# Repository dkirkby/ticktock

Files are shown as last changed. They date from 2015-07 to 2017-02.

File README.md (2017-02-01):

# Precision Pendulum Clock Metrology

This repository contains electronics schematics and a printed circuit board design for precision metrology of a pendulum clock.

The corresponding microcontroller firmware and unix server backend are hosted [here](https://github.com/captainkirkby/Gears).

For an overview of this project, see [this excerpt](https://github.com/dkirkby/ticktock/blob/master/InterfaceMagazineFall2015.pdf) from the Fall 2015 Issue of the [CalIT2](http://www.calit2.uci.edu) Interface Magazine.

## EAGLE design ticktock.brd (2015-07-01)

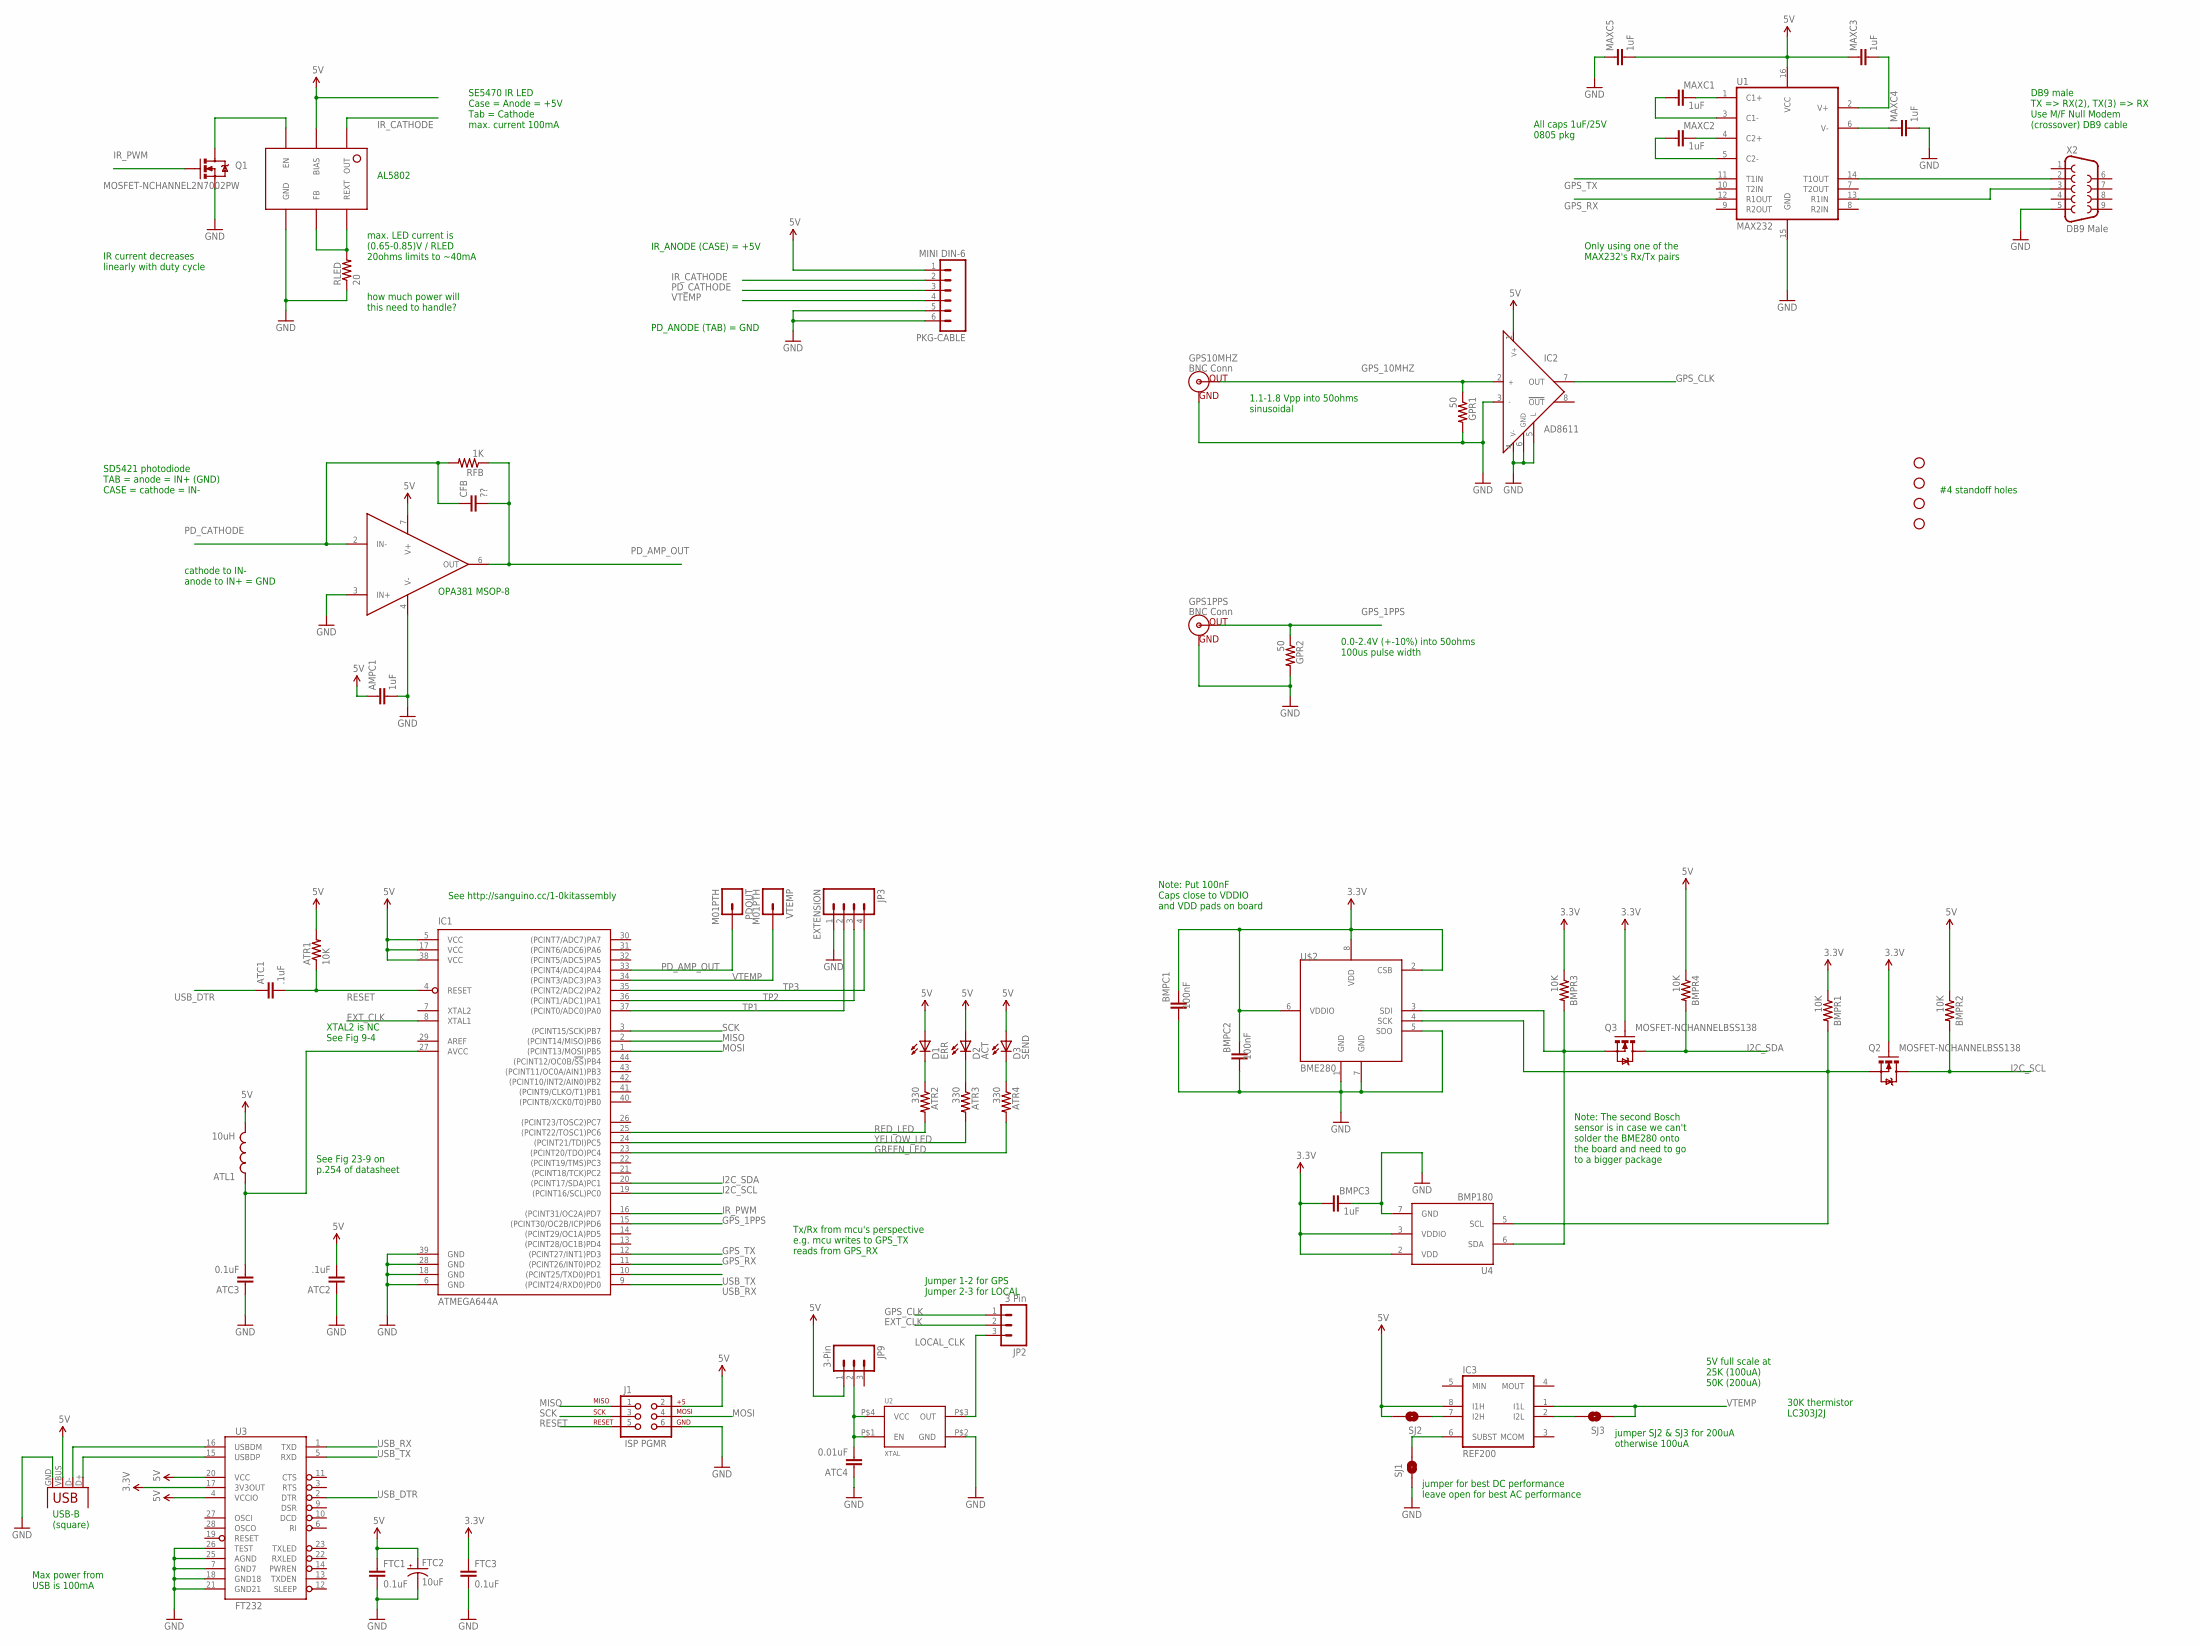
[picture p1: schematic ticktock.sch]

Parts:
AMPC1: 1uF; 0805
ATC1, ATC2: .1uF; 0805
ATC3: 0.1uF; 0805
ATC4: 0.01uF; 0805
ATL1: 10uH; 0805
ATR1: 10K; 0805
ATR2, ATR3, ATR4: 330; 0805
BMPC1, BMPC2: 100nF; 0805
BMPC3: 1uF; 0805
BMPR1, BMPR2, BMPR3, BMPR4: 10K; 0805
CFB: ??; 0805
D1: ERR; LED-1206
D2: ACT; LED-1206
D3: SEND; LED-1206
FTC1, FTC3: 0.1uF; 0805
FTC2: 10uF; EIA3216
GPR1, GPR2: 50; 0805
GPS1PPS, GPS10MHZ: BNC Conn; BNC
IC1: ATMEGA644A; TQFP44
IC2: AD8611; MSOP08
IC3: REF200; SO08
IC4: OPA381; MSOP08
IC5: AL5802
J1: ISP PGMR; 2X3-NS
JP1: Square USB; USB-B-PTH
JP2: 3 Pin; 1X03_LOCK
JP3: EXTENSION; 1X04_LOCK
JP9: 3-Pin; 1X03_LOCK
MAXC1, MAXC2, MAXC3, MAXC4, MAXC5: 1uF; 0805
PDOUT: M01PTH; 1X01
PKG-CABLE: MINI DIN-6; MINI-DIN6
Q1: MOSFET-NCHANNEL2N7002PW; SOT323
Q2, Q3: MOSFET-NCHANNELBSS138; SOT23
RFB: 1K; 0805
RLED: 20; 0805
SJ1, SJ2, SJ3: SOLDERJUMPERNO; SJ_2S-NO
STANDOFF1, STANDOFF2, STANDOFF3, STANDOFF4: STAND-OFF
U1: MAX232; SO016
U2: XTAL; CRYSTAL-SMD-7X5
U3: FT232; SSOP28DB
U4: BMP180
U$2: BME280
VTEMP: M01PTH; 1X01
X2: DB9 Male; DB9_MALE

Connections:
3.3V: BMPC1.2, BMPC2.2, BMPC3.1, BMPR1.1, BMPR3.1, FTC3.1, Q2.1 (G), Q3.1 (G), U3.17 (3V3OUT), U4.2 (VDD), U4.3 (VDDIO), U$2.2 (CSB), U$2.6 (VDDIO), U$2.8 (VDD)
5V: AMPC1.1, ATC2.2, ATL1.2, ATR1.2, BMPR2.1, BMPR4.1, D1.A, D2.A, D3.A, FTC1.1, FTC2.A (+), IC1.5 (VCC), IC1.17 (VCC), IC1.38 (VCC), IC2.1 (V+), IC3.8 (I1H), IC4.7 (V+), IC5.BIAS, J1.2, JP1.VBUS, JP9.1, MAXC3.1, MAXC5.2, PKG-CABLE.1, SJ2.2, U1.16 (VCC), U3.4 (VCCIO), U3.20 (VCC)
EXT_CLK: IC1.8 (XTAL1), JP2.2
GND: AMPC1.2, ATC2.1, ATC3.1, ATC4.1, BMPC1.1, BMPC2.1, BMPC3.2, FTC1.2, FTC2.C (-), FTC3.2, GPR1.2, GPR2.2, GPS1PPS.GND, GPS10MHZ.GND, IC1.6 (GND), IC1.18 (GND), IC1.28 (GND), IC1.39 (GND), IC2.3 (IN-), IC2.4 (V-), IC2.5 (L), IC2.6 (GND), IC4.3 (IN+), IC4.4 (V-), IC5.GND, J1.6, JP1.GND, JP3.1, MAXC4.2, MAXC5.1, PKG-CABLE.5, PKG-CABLE.6, Q1.2 (S), RLED.1, SJ1.1, U1.15 (GND), U2.P$2 (GND), U3.7 (GND7), U3.18 (GND18), U3.21 (GND21), U3.25 (AGND), U3.26 (TEST), U4.7 (GND), U$2.1 (GND), U$2.5 (SDO), U$2.7 (GND), X2.5
GPS_1PPS: GPR2.1, GPS1PPS.S (OUT), IC1.15 ((PCINT30/OC2B/ICP)PD6)
GPS_10MHZ: GPR1.1, GPS10MHZ.S (OUT), IC2.2 (IN+)
GPS_CLK: IC2.7 (OUT), JP2.1
GPS_RX: IC1.11 ((PCINT26/INT0)PD2), U1.12 (R1OUT)
GPS_TX: IC1.12 ((PCINT27/INT1)PD3), U1.11 (T1IN)
GREEN_LED: ATR4.2, IC1.23 ((PCINT20/TDO)PC4)
I2C_SCL: BMPR2.2, IC1.19 ((PCINT16/SCL)PC0), Q2.3 (D)
I2C_SDA: BMPR4.2, IC1.20 ((PCINT17/SDA)PC1), Q3.3 (D)
IR_CATHODE: IC5.OUT, PKG-CABLE.2
IR_PWM: IC1.16 ((PCINT31/OC2A)PD7), Q1.1 (G)
LOCAL_CLK: JP2.3, U2.P$3 (OUT)
MISO: IC1.2 ((PCINT14/MISO)PB6), J1.1
MOSI: IC1.1 ((PCINT13/MOSI)PB5), J1.4
unnamed: IC5.EN, Q1.3 (D)
unnamed: IC5.FB, IC5.REXT, RLED.2
unnamed: MAXC1.2, U1.1 (C1+)
unnamed: MAXC1.1, U1.3 (C1-)
unnamed: MAXC2.2, U1.4 (C2+)
unnamed: MAXC2.1, U1.5 (C2-)
unnamed: MAXC3.2, U1.2 (V+)
unnamed: U1.14 (T1OUT), X2.2
unnamed: MAXC4.1, U1.6 (V-)
unnamed: U1.13 (R1IN), X2.3
unnamed: JP1.D-, U3.16 (USBDM)
unnamed: JP1.D+, U3.15 (USBDP)
unnamed: ATC3.2, ATL1.1, IC1.27 (AVCC)
unnamed: IC3.6 (SUBST), SJ1.2
unnamed: BMPR1.2, Q2.2 (S), U4.5 (SCL), U$2.4 (SCK)
unnamed: ATR4.1, D3.C
unnamed: IC3.7 (I2H), SJ2.1
unnamed: IC3.2 (I2L), SJ3.2
unnamed: ATR3.1, D2.C
unnamed: ATR2.1, D1.C
unnamed: ATC4.2, JP9.2, U2.P$1 (EN), U2.P$4 (VCC)
unnamed: BMPR3.2, Q3.2 (S), U4.6 (SDA), U$2.3 (SDI)
PD_AMP_OUT: CFB.2, IC1.33 ((PCINT4/ADC4)PA4), IC4.6 (OUT), PDOUT.1, RFB.1
PD_CATHODE: CFB.1, IC4.2 (IN-), PKG-CABLE.3, RFB.2
RED_LED: ATR2.2, IC1.25 ((PCINT22/TOSC1)PC6)
RESET: ATC1.2, ATR1.1, IC1.4 (RESET), J1.5
SCK: IC1.3 ((PCINT15/SCK)PB7), J1.3
TP1: IC1.37 ((PCINT0/ADC0)PA0), JP3.2
TP2: IC1.36 ((PCINT1/ADC1)PA1), JP3.3
TP3: IC1.35 ((PCINT2/ADC2)PA2), JP3.4
USB_DTR: ATC1.1, U3.2 (DTR)
USB_RX: IC1.9 ((PCINT24/RXD0)PD0), U3.1 (TXD)
USB_TX: IC1.10 ((PCINT25/TXD0)PD1), U3.5 (RXD)
VTEMP: IC1.34 ((PCINT3/ADC3)PA3), IC3.1 (I1L), PKG-CABLE.4, SJ3.1, VTEMP.1
YELLOW_LED: ATR3.2, IC1.24 ((PCINT21/TDI)PC5)

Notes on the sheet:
max. LED current is (0.65-0.85)V / RLED 20ohms limits to ~40mA
SE5470 IR LED Case = Anode = +5V Tab = Cathode max. current 100mA
how much power will this need to handle?
IR current decreases linearly with duty cycle
AL5802
All caps 1uF/25V 0805 pkg
Only using one of the MAX232's Rx/Tx pairs
DB9 male TX => RX(2), TX(3) => RX Use M/F Null Modem (crossover) DB9 cable
USB-B (square)
Max power from USB is 100mA
See Fig 23-9 on p.254 of datasheet
IR_ANODE (CASE) = +5V
XTAL2 is NC See Fig 9-4
See http://sanguino.cc/1-0kitassembly
Jumper 1-2 for GPS Jumper 2-3 for LOCAL
0.0-2.4V (+-10%) into 50ohms 100us pulse width
1.1-1.8 Vpp into 50ohms sinusoidal
OPA381 MSOP-8
cathode to IN- anode to IN+ = GND
SD5421 photodiode TAB = anode = IN+ (GND) CASE = cathode = IN-
PD_ANODE (TAB) = GND
jumper for best DC performance leave open for best AC performance
jumper SJ2 & SJ3 for 200uA otherwise 100uA
5V full scale at 25K (100uA) 50K (200uA)
30K thermistor LC303J2J
#4 standoff holes
Note: Put 100nF Caps close to VDDIO and VDD pads on board
Note: The second Bosch sensor is in case we can't solder the BME280 onto the board and need to go to a bigger package
Tx/Rx from mcu's perspective e.g. mcu writes to GPS_TX reads from GPS_RX

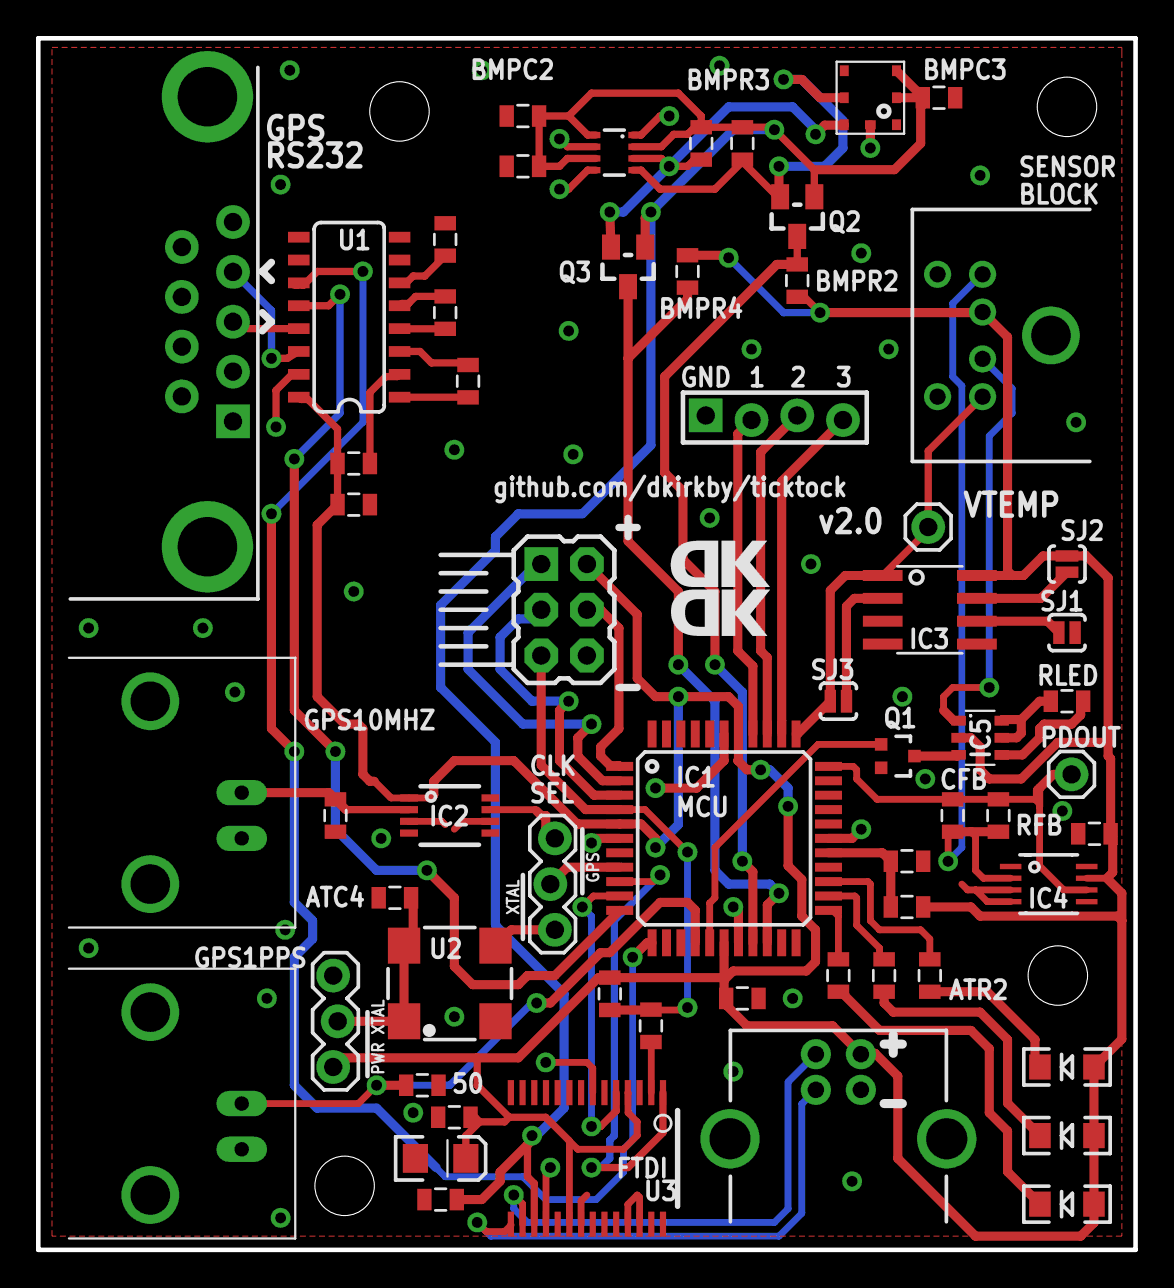
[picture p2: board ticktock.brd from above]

Board: 2 copper layers, 61.0 x 67.3 mm, 64 parts (0 on the bottom side), 52 nets.

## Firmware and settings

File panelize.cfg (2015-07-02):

# This configuration file demonstrates panelizing a single job.

##############################################################################
# In the [DEFAULT] section you can create global names to save typing the same
# directory name, for example, over and over.
##############################################################################
[DEFAULT]

# Change projdir to wherever your project files are, for example:
#
#   projdir = /home/stuff/projects/test
#
# or relative pathname from where you are running GerbMerge
#
#   projdir = testdata
#
# or if all files are in the current directory (as in this example):
#
#   projdir = .
projdir = .

# For convenience, this is the base name of the merged output files.
MergeOut = merge9

#############################################################################
# The [Options] section defines settings that control how the input files are
# read and how the output files are generated.
#############################################################################
[Options]

################################################################
#
#               Settings that are very important
#
################################################################

# Option indicating name of file that maps Excellon tool codes to drill sizes.
# This is not necessary if the Excellon files have embedded tool sizes, or if a
# tool list is specified as part of the job description. The ToolList option
# here is the "last resort" for mapping tool codes to tool sizes. Most recent
# PCB programs embed drill size information right in the Excellon file, so this
# option should not be necessary and can be commented out.
#ToolList=proj1.drl

# Optional indication of the number of decimal places in input Excellon drill
# files. The default is 4 which works for recent versions of Eagle (since
# version 4.11r12), as well as Orcad and PCB. Older versions of Eagle use 3
# decimal places.
#ExcellonDecimals = 4

################################################################
#
#             Settings that are somewhat important
#
################################################################

# Which layers to draw cut lines on. Omit this option or set to 'None' for no
# cut lines. Cut lines are borders around each job that serve as guides for
# cutting the panel into individual jobs. Option 'CutLineWidth' sets the
# thickness of these cut lines.
#
# NOTE: Layer names are ALL LOWERCASE, even if you define them with uppercase
# letters below.
CutLineLayers = *topsilkscreen

# Which layers to draw crop marks on. Omit this option or set to 'None' for no
# crop marks. Crop marks are small L-shaped marks at the 4 corners of the final
# panel. These practically define the extents of the panel and are required by
# some board manufacturers. Crop marks are also required if you want to leave
# extra space around the final panel for tooling or handling.  Option
# 'CropMarkWidth' sets the thickness of these crop marks.
#
# NOTE: Layer names are ALL LOWERCASE, even if you define them with uppercase
# letters below.
CropMarkLayers = *topsilkscreen

# Set this option to the name of a file in which to write a Gerber fabrication
# drawing. Some board manufacturers require a fabrication drawing with panel
# dimensions and drill hit marks and drill legend. There's no harm in creating
# this file...you can ignore it if you don't need it.
FabricationDrawingFile = %(projdir)s/%(mergeout)s/%(mergeout)s.fab

# If FabricationDrawingFile is specified, you can provide an optional file name
# of a file containing arbitrary text to add to the fabrication drawing. This
# text can indicate manufacturing information, contact information, etc.
#FabricationDrawingText = %(projdir)s/fabdwg.txt

# Option to generate leading zeros in the output Excellon drill file, i.e., to
# NOT use leading-zero suppression. Some Gerber viewers cannot properly guess
# the Excellon file format when there are no leading zeros.  Set this option to
# 1 if your Gerber viewer is putting the drill holes in far off places that do
# not line up with component pads.
ExcellonLeadingZeros = 0

# Optional additional Gerber layer on which to draw a rectangle defining the
# extents of the entire panelized job. This will create a Gerber file (with
# name specified by this option) that simply contains a rectangle defining the
# outline of the final panel. This outline file is useful for circuit board
# milling to indicate a path for the router tool. There's no harm in creating
# this file...you can ignore it if you don't need it.
OutlineLayerFile = %(projdir)s/%(mergeout)s/%(mergeout)s.oln

# Optional additional Gerber layer on which to draw horizontal and vertical
# lines describing where to score (i.e., V-groove) the panel so that jobs
# can easily snap apart. These scoring lines will be drawn half-way between
# job borders.
ScoringFile = %(projdir)s/%(mergeout)s/%(mergeout)s.sco
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

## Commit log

2013-12-06 Add schematic with 8.5x11 landscape frame
    [ticktock.sch]
2013-12-06 Add 2x2 grid of schematic frames
    [ticktock.sch]
2013-12-06 Add power nodes from sparkfun git library
    [ticktock.sch]
2013-12-07 add some components for the LED driver
    [ticktock.sch]
2013-12-07 create initial board file
    [ticktock.brd]
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2013-12-18 Finish IR led current source
    [ticktock.brd, ticktock.sch]
2013-12-18 add mini-DIN6 connector to package
    [ticktock.brd, ticktock.sch]
2013-12-18 Add RS232 transceiver and DB9 connector
    [ticktock.brd, ticktock.sch]
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2013-12-18 Add BNC connectors and AVR644
    [ticktock.brd, ticktock.sch]
2013-12-18 Add FTDI USB interface
    [ticktock.brd, ticktock.sch]
2013-12-18 Add MCU power and reset
    [ticktock.brd, ticktock.sch]
2013-12-19 Add some MCU connections
    [ticktock.brd, ticktock.sch]
2013-12-19 Add local 10MHz osc and local/gps jumper block
    [ticktock.brd, ticktock.sch]
2013-12-19 Add comparator for GPS 10MHz
    [ticktock.brd, ticktock.sch]
2013-12-19 Add 50ohm termination on 1PPS input
    [ticktock.brd, ticktock.sch]
2013-12-19 Add op-amp schematic (missing actual op-amp)
    [ticktock.brd, ticktock.sch]
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2013-12-20 Add thermistor 100/200uA current source
    [ticktock.brd, ticktock.sch]
2013-12-20 Add BMP180 and level shifters
    [ticktock.brd, ticktock.sch]
2013-12-20 wire up analog inputs and I2C to MCU
    [ticktock.brd, ticktock.sch]
2013-12-20 Add 3 indicator LEDs
    [ticktock.brd, ticktock.sch]
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2013-12-20 Add header for fallback BMP085 carrier board
    [ticktock.brd, ticktock.sch]
2013-12-20 Group sensors on mini-DIN
    [ticktock.brd, ticktock.sch]
2013-12-20 Recenter subcircuits in schematic
    [ticktock.sch]
2013-12-20 Add thermistor info in a label
    [ticktock.sch]
2013-12-20 First pass at board placement
    [ticktock.brd]
2013-12-20 Fix USB connector label (A -> B)
    [ticktock.sch]
2013-12-20 Add four 2.8mm PCB mounting holes
    [ticktock.brd]
2013-12-21 Add 0.05" grid, make tDocu layer yellow
    [ticktock.brd]
2013-12-21 Move connectors so their silkscreens fit on pcb
    [ticktock.brd]
2013-12-21 Replace existing holes with SparkFun #4 standoff holes
    [ticktock.brd, ticktock.sch]
2013-12-21 Add a bottom ground plane
    [ticktock.brd]
2013-12-21 Remove ground plane for now since it only cleans up through hole ground connections
    [ticktock.brd]
2013-12-21 Start placing around origin
    [ticktock.brd]
2013-12-21 fix schematic broken connections
    [ticktock.brd, ticktock.sch]
2013-12-21 Add power jumper for local 10MHz
    [ticktock.brd, ticktock.sch]
2013-12-21 finish first pass at placement
    [ticktock.brd]
2013-12-21 Trim board to 2.4 x 2.6 inches
    [ticktock.brd]
2013-12-22 Relaid out Barometric Pressure Sensor part of board
    [ticktock.brd]
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2013-12-23 swap LEDs and resistors to get LEDs into PCB corner
    [ticktock.brd, ticktock.sch]
2013-12-23 change grid from 0.05 to 0.01
    [ticktock.brd]
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2013-12-23 Route Barometric Pressure Sensor part of board.
    [ticktock.brd]
2013-12-23 Route easy bits of MAX232 transceiver part of board.
    [ticktock.brd]
2013-12-23 Route 5V power traces.
    [ticktock.brd]
2013-12-23 Route 5V under chip.
    [ticktock.brd]
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2013-12-24 Fix traces around RS232 pins to use vias instead.
    [ticktock.brd]
2013-12-24 Replace SO8 package of ultrafast comparator with MSOP8 package.
    [ticktock.brd, ticktock.sch]
2013-12-24 Add power to pin 4 of FTDI chip.
    [ticktock.brd, ticktock.sch]
2013-12-24 Fix ERC and DRC complaints. Connect accidentally unconnected nets.
    [ticktock.brd, ticktock.sch]
2013-12-24 add bottom ground plane
    [ticktock.brd]
2013-12-24 ease ground plane into a tight spot
    [ticktock.brd]
2013-12-24 Add top ground plane
    [ticktock.brd]
2013-12-24 hand route ground vias
    [ticktock.brd]
2013-12-24 only 2 airwires left...
    [ticktock.brd]
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2013-12-24 Fix up DRC clearance complaints.
    [ticktock.brd]
2013-12-24 Modify board to conform to SparkFun's DRC file.
    [ticktock.brd]
2013-12-24 Generate Gerber files for board.
    [ticktock.GBL, ticktock.GBO, ticktock.GBS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]
2013-12-24 Modify board to generate gerber file without edge.
    [ticktock.brd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]
2013-12-24 Increse board dimension outline to 10 mil.
    [ticktock.brd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]
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2015-06-20 Remove BMP carrier board header and Pull RS232 connector back to PCB edge
    [ticktock.brd, ticktock.sch]
2015-06-20 Move 10uF cap closer to FTDI chip
    [ticktock.brd]
2015-06-20 Replace DB9 female connector with a male one
    [ticktock.brd, ticktock.sch]
2015-06-20 Flip USB_TX and USB_RX in schematic
    [ticktock.brd, ticktock.sch]
2015-06-20 Flip USB_TX and USB_RX in board
    [ticktock.brd]
2015-06-21 Drop in BME280 (remove BMP180)
    [ticktock.brd, ticktock.sch]
2015-06-21 Place new BME280 and old BMP180 on board
    [ticktock.brd, ticktock.sch]
2015-06-25 Clean up DRC errors
    [ticktock.brd]
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2015-06-25 Clean up ERC and add pin 1 marker on BME280
    [ticktock.brd, ticktock.sch]
2015-06-25 Add silkscreen indicating RS232 polarity and ISP header direction
    [ticktock.brd]
2015-06-25 Relabel USB_TX and USB_RX to be consistent with MCU's perspective
    [ticktock.brd, ticktock.sch]
2015-06-25 Reroute right angle wire
    [ticktock.brd]
2015-06-25 Add silkscreen for MAX232
    [ticktock.brd, ticktock.sch]
2015-06-26 Start working on silkscreen
    [ticktock.brd, ticktock.sch]
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2015-06-26 More work on silkscreen
    [ticktock.brd, ticktock.sch]
2015-06-26 Shuffle tight parts/silkscreens around
    [ticktock.brd, ticktock.sch]
2015-06-26 Modify Silkscreen for AL5802
    [ticktock.brd, ticktock.sch]
2015-06-26 Modify Silkscreen for OPA381
    [ticktock.brd, ticktock.sch]
2015-06-26 Modify Silkscreen for FT232
    [ticktock.brd, ticktock.sch]
2015-06-26 Modify Silkscreen for N-Channel MOSFET
    [ticktock.brd, ticktock.sch]
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2015-06-28 Add logo, url, and version number. Pour ground around BNC connectors
    [ticktock.brd]
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2015-06-29 Move silkscreens of connectors away from the board edge
    [ticktock.brd, ticktock.sch]
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2015-06-30 Fix FreeDFM.org complaints about skinny silkscreens
    [ticktock.brd, ticktock.sch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]
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2015-07-01 Add gerbmerge config file for panelizing gerber files
    [panelize.cfg]
2015-07-02 Confirm gerbmerge output visually with gerbv and programatically with FreeDFM. Ready to fab
    [panelize.cfg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]

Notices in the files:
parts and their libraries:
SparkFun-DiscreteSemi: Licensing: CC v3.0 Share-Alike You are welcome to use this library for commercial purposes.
